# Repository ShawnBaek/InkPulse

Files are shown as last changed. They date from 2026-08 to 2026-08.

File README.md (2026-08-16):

# InkPulse

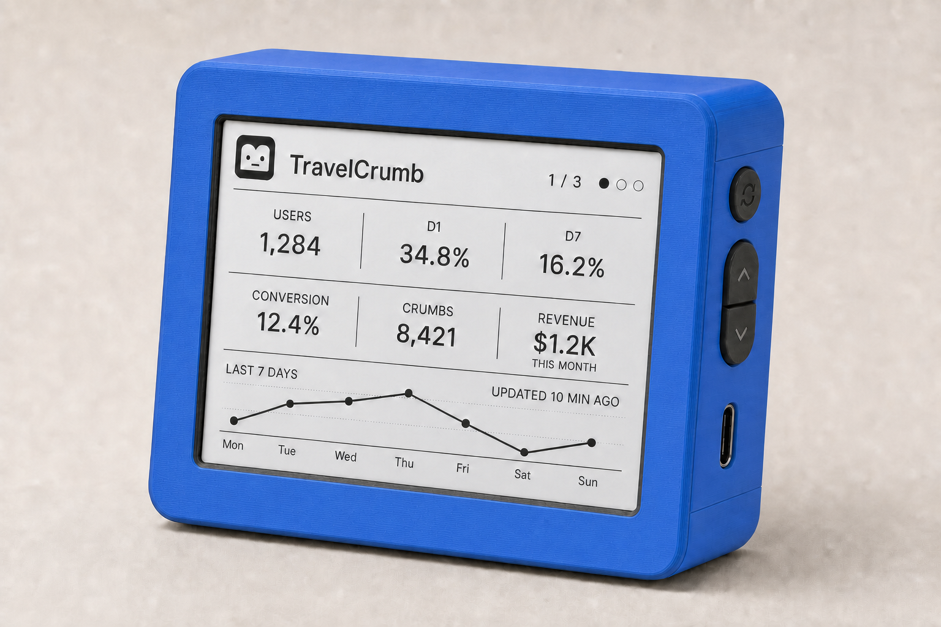
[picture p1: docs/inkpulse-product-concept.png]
Example product analytics dashboard


InkPulse is a compact desktop device that shows configurable product metrics, Google Analytics 4 retention data, and current-month App Store proceeds on a 4.2-inch e-paper display. The iPhone companion app retrieves and calculates the data, renders a 400 × 300 monochrome dashboard, and sends it to Embedded Swift firmware over Bluetooth Low Energy.

> This repository is a **v0.1 product, hardware, and 3D-printing concept**. The electrical design and battery-life target are not production specifications until they have been validated on a physical prototype.

The bundled product rendering illustrates one app-specific configuration. The app icon, product name, metric labels, and values are replaceable without changing the enclosure or display pipeline.

## Product model

| Item | v0.1 model |
| --- | --- |
| Project name | InkPulse |
| Product face | Configurable application analytics dashboard |
| Model | InkPulse Model 42 |
| Purpose | At-a-glance retention, conversion, activity, and revenue monitoring |
| Display | 4.2-inch, 400 × 300, black-and-white e-paper |
| Connectivity | Bluetooth Low Energy first; Wi-Fi is a later option |
| Update path | The iPhone renders and sends a compressed 1-bit frame |
| Controls | One action button plus a two-way previous/next rocker |
| Enclosure | Approximately 125 × 101 × 40 mm, landscape desktop format |
| Colorway | Cobalt-blue front and rear enclosure with matte-black controls and screen gasket |
| Power | USB-C 5 V or one removable protected 3.7 V 18650 cell |
| Firmware | Embedded Swift with ESP-IDF C interoperability |

The default dashboard contains:

- Total registered users
- Day 1 and Day 7 retention
- New-user-to-primary-action conversion
- Successful primary actions in the selected period
- Estimated App Store proceeds for the current calendar month
- Multi-app pagination and the current page position
- Last-successful-sync freshness, such as `UPDATED 10 MIN AGO`
- Battery and connection status

## Metric definitions

The display uses product-specific metrics instead of a generic GA4 `EVENTS` total.

| Display label | Definition | Initial data source |
| --- | --- | --- |
| `USERS` | Total registered application accounts | Application backend |
| `D1` | Percentage of a new-user cohort that returns on the next calendar day | GA4 cohort report |
| `D7` | Percentage of a new-user cohort that returns on calendar day 7 | GA4 cohort report |
| `CONVERSION` | New users who complete the application's primary action within 24 hours ÷ all new users in the same cohort | Derived from `first_open` and an app-defined success event |
| `ACTIVITY` | Successful primary actions in the selected period | GA4 `eventCount` filtered to the app-defined success event; the backend should become the production source of truth |
| `REVENUE` | Estimated developer proceeds in the current calendar month, after applicable taxes and Apple's commission | App Store Connect Sales and Trends proceeds report |
| `UPDATED … AGO` | Elapsed time since the last fully successful fetch and rendered-frame update | Companion-app sync state |

`EVENTS` is not recommended because it combines unrelated analytics events such as screen views, sessions, and button taps. `ACTIVITY` should represent the app-specific behavior the product is intended to encourage.

See [Product metrics](docs/METRICS.md) for the recommended dashboard hierarchy, formulas, and future pages.

## System architecture

```mermaid
flowchart LR
    GA4["Google Analytics Data API"] --> IOS["iPhone companion app\nSwiftUI + Core Bluetooth"]
    BACKEND["Application backend"] --> IOS
    APPSTORE["App Store Connect\nSales and Trends"] --> IOS
    IOS -->|"BLE: compressed 1-bit frame"| DEVICE["ESP32-C6\nEmbedded Swift"]
    DEVICE --> CACHE["Cached app pages\n1 / 3"]
    DEVICE -->|"SPI"| EINK["4.2-inch e-paper\n400 x 300"]
```

The device never stores Google OAuth tokens, service-account keys, or App Store Connect credentials. The iPhone app or a separate backend handles API authentication and sends only display pixels and minimal configuration to the device.

## Hardware specification

| Component | Proposed part | Key specification / reason |
| --- | --- | --- |
| MCU | Seeed Studio XIAO ESP32-C6 | 160 MHz RISC-V, 512 KB SRAM, 4 MB Flash, BLE 5.3, Wi-Fi 6, USB-C, and single-cell battery charging |
| Display | Waveshare 4.2-inch e-Paper Module V2 (B/W) | 400 × 300, SPI, partial refresh, and near-zero display retention power |
| Battery | Protected 18650 Li-ion, 3.7 V, 2,500–3,500 mAh | Removable and capable of cable-free operation |
| Battery connection | MPD BH-18650-W protected-cell holder | 77.7 × 20.9 × 21.31 mm chassis-mount holder with wire leads |
| Action input | Omron B3F-1000 tactile switch | 6 × 6 × 4.3 mm, 0.98 N, normally open |
| Navigation input | Printed two-way rocker over two Omron B3F-1000 switches | Previous/next app dashboard with separate physical contacts |
| Power switch | C&K 1101M2S5AQE2 slide switch | Right-angle SPDT with Q silver contacts rated 6 A at 28 V DC, used as a battery disconnect |
| Enclosure | 3D-printed PETG with M2 inserts and screws | Cobalt-blue front/rear shell, matte-black controls and screen gasket, electronics tray, and positively retained battery door |

### Power behavior

- With USB-C connected, the XIAO ESP32-C6 operates from USB power and charges the single-cell battery through its onboard power-management circuit.
- With USB-C disconnected, it operates from the protected 18650 cell connected to the BAT input.
- The MPD holder is designed for protected 18650 cells. Confirm the purchased cell's diameter, length, polarity, and protection circuit before installation.
- **Never charge alkaline AA/AAA cells, unprotected cells, or mixed cell types/states.** The v0.1 prototype is designed for one protected rechargeable Li-ion cell only.
- The slide switch disconnects the battery branch; USB-C can still power the controller while the battery is disconnected.
- Before designing a production PCB, validate reverse-polarity protection, branch overcurrent protection, charging temperature, actual charge current, connector polarity, and enclosure temperature.
- The initial battery-life target is at least 30 days with a 3,000 mAh cell and low-power scheduling. This is a target, not a verified claim.

See the [bill of materials](hardware/BOM.csv) and [wiring plan](hardware/WIRING.md) for component and connection details.

## Prototype purchase guide

The links below are reference purchase sources for the mechanically locked v0.1 parts. Indicative prices were checked on August 16, 2026, are shown in USD, and exclude shipping, tax, duties, tools, and any commercial 3D-printing service. Prices and availability vary by destination; these are not affiliate links.

| Part | Qty used | Reference purchase link | Listed price | Allocated to one device |
| --- | ---: | --- | ---: | ---: |
| Seeed Studio XIAO ESP32-C6 | 1 | [Seeed Studio](https://www.seeedstudio.com/Seeed-Studio-XIAO-ESP32C6-p-5884.html) | $5.20 each | $5.20 |
| Waveshare 4.2-inch e-Paper Module V2, black/white | 1 | [Waveshare](https://www.waveshare.com/4.2inch-e-paper-module.htm) | $34.99 each | $34.99 |
| EBL protected button-top 18650, 3.7 V, 3,000 mAh | 1 cell | [EBL official store](https://www.eblofficial.com/products/brc-18650-batteries) | $9.26 per 2-pack | $4.63 |
| MPD BH-18650-W holder | 1 | [DigiKey](https://www.digikey.com/en/products/detail/mpd-memory-protection-devices/BH-18650-W/3029217) | $3.64 each | $3.64 |
| C&K 1101M2S5AQE2 slide switch | 1 | [DigiKey](https://www.digikey.com/en/products/detail/c-k/SWITCH-1101M2S5AQE2/99505) | $8.48 each | $8.48 |
| Omron/Aratas B3F-1000 tactile switch | 3 | [DigiKey](https://www.digikey.com/en/products/detail/aratas-formerly-omron-components/B3F-1000/33150) | $0.35 each | $1.05 |
| Blue and black 1.75 mm PETG | About 140 g total | [Prusament PETG color range](https://prusament.com/materials/prusament-petg/) | $29.99 per 1 kg spool | About $4–5 |

The locked electronic parts total approximately **$57.99 per device**. Allow another **$12–22** per device for the allocated PETG, PTC fuse, perfboard or carrier PCB, display harness, wire, insulation, inserts, screws, nuts, foam, and consumables. The resulting **one-device prototype material estimate is $70–80**.

A first order is more expensive because the reference battery is sold as a two-pack and the blue/black enclosure requires two filament colors. Expect approximately **$120–155 at checkout** when buying two full PETG spools and normal retail packs of the remaining hardware. Subsequent units consume only a fraction of those supplies.

Before ordering, confirm that the display is the 103 × 78.5 mm black-and-white module with its SPI driver board—not a raw panel, Pico-specific board, or multicolor variant. The battery link is a dimensional reference, not an electrical certification: measure the purchased protected cell, confirm polarity and holder fit, and perform supervised charging and thermal validation. The PTC, harness, carrier, fasteners, and insulation remain intentionally supplier-neutral until the first physical fit test locks their exact models.

## 3D model

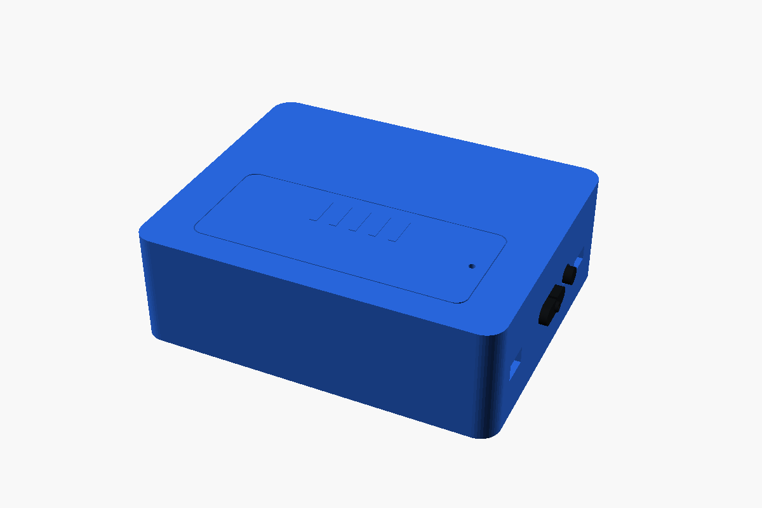
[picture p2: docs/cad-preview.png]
InkPulse OpenSCAD assembly preview


InkPulse enclosure exploded view

The repository includes the editable OpenSCAD source and printable STL exports.

- [`hardware/cad/InkPulse.scad`](hardware/cad/InkPulse.scad) — parametric source model
- `hardware/cad/stl/front-bezel.stl` — front bezel
- `hardware/cad/stl/rear-shell.stl` — rear enclosure with case standoffs and switch retention
- `hardware/cad/stl/electronics-tray.stl` — captured hardware tray and display foam lands
- `hardware/cad/stl/battery-door.stl` — rail-guided, screw-retained battery door
- `hardware/cad/stl/action-button.stl` — action/refresh button cap
- `hardware/cad/stl/navigation-rocker.stl` — pivoting previous/next rocker
- `hardware/cad/stl/switch-carrier.stl` — three-switch carrier and rocker axle support
- [`hardware/cad/README.md`](hardware/cad/README.md) — print orientation and STL export instructions
- [`hardware/cad/VALIDATION.md`](hardware/cad/VALIDATION.md) — mesh, component-stack, slicing, and physical-validation evidence

The model uses manufacturer dimensions for the Waveshare display PCB, XIAO ESP32-C6, MPD battery holder, Omron switches, and C&K power switch. It also contains visual-only component envelopes for collision inspection. That makes the repository suitable for a first engineering print, but it is not proof of physical fit: measure the purchased revisions, print the fit-critical parts, and complete an electrical and thermal prototype before treating the enclosure as production-ready.

## Software boundary

### iPhone companion app

1. The user connects the appropriate GA4 property, application backend, and App Store Connect reporting source.
2. The app reads cohort data, primary-action activity, registered-user totals, and current-month proceeds.
3. It calculates the product metrics and renders a 400 × 300 monochrome dashboard.
4. It packages one or more named app pages, compresses each frame, and sends them in BLE characteristic chunks.

### Embedded Swift firmware

1. ESP-IDF provides the BLE and SPI drivers.
2. Embedded Swift owns pairing, frame validation, and the device state machine.
3. The firmware caches the verified pages and moves to the previous or next app when the rocker is pressed.
4. It applies only complete frames to the e-paper display and then returns to deep sleep.
5. The firmware pins its Swift nightly toolchain version because the Embedded Swift ABI is not yet stable.

## v0.1 acceptance criteria

- [ ] Bring up an Embedded Swift LED and SPI test on XIAO ESP32-C6
- [ ] Show 400 × 300 full-refresh and partial-refresh test patterns
- [ ] Transfer a 15 KB frame from iPhone over BLE and validate its CRC
- [ ] Display real registered users, D1, D7, primary-action conversion, activity count, and current-month proceeds
- [ ] Cache at least three app pages and navigate them with wraparound previous/next controls
- [ ] Validate USB-C charging, battery-only boot, and low-voltage shutdown
- [ ] Print the enclosure and check display, USB-C, action button, rocker, and battery-door tolerances
- [ ] Measure a 24-hour power profile and a 30-day projected profile

## Design references

- [Embedded Swift documentation](https://docs.swift.org/embedded/documentation/embedded/) — language mode and toolchain scope
- [Integrating Embedded Swift with platforms](https://docs.swift.org/embedded/documentation/embedded/integratingwithplatforms/) — RISC-V ESP32-C3/C6/P4 support
- [Swift Embedded Examples](https://github.com/swiftlang/swift-embedded-examples) — ESP32-C6 and ESP-IDF examples
- [XIAO ESP32-C6 documentation](https://wiki.seeedstudio.com/xiao_esp32c6_getting_started/) — memory, wireless, USB-C, and battery power
- [Waveshare 4.2-inch e-Paper documentation](https://www.waveshare.com/wiki/4.2inch_e-Paper_Module_Manual) — dimensions, resolution, SPI, and refresh behavior
- [MPD BH-18650-W drawing](https://www.memoryprotectiondevices.com/datasheets/BH-18650-W/BH-18650-W-datasheet.pdf) — protected-cell holder envelope and mounting pattern
- [Omron B3F tactile-switch datasheet](https://omronfs.omron.com/en_US/ecb/products/pdf/en-b3f.pdf) — action and navigation switch dimensions and travel
- [C&K 1000 Series slide-switch datasheet](https://www.ckswitches.com/media/1429/1000.pdf) — `1101M2S5AQE2` dimensions, ordering code, and Q-contact rating
- [Google Analytics Data API quickstart](https://developers.google.com/analytics/devguides/reporting/data/v1/quickstart) — GA4 authentication and `runReport`
- [App Store Connect Sales and Trends metrics](https://developer.apple.com/help/app-store-connect/reference/reporting/sales-and-trends-metrics-and-dimensions/) — proceeds definition and reporting dimensions
- [Apple Core Bluetooth](https://developer.apple.com/documentation/corebluetooth) — iPhone BLE communication

## Repository structure

```text
InkPulse/
├── docs/                  # Product renderings, App Store icon, and diagrams
├── hardware/
│   ├── BOM.csv            # v0.1 bill of materials
│   ├── WIRING.md          # Power and SPI connections
│   └── cad/               # OpenSCAD source and STL exports
└── README.md
```

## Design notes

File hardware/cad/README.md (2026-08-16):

# InkPulse enclosure CAD

`InkPulse.scad` is the parametric source of truth. It models a 125 × 101 × 40 mm landscape, FDM-printable enclosure around specific component envelopes. This is a prototype design: physical print and assembly validation are required before production use.

## Component envelopes

| Part | Envelope / feature |
| --- | --- |
| Waveshare 4.2-inch B/W V2 e-Paper | 103.0 × 78.5 × 8.5 mm PCB envelope; 84.8 × 63.6 mm active area; 90.1 × 77.0 × 1.18 mm raw panel |
| Seeed XIAO ESP32-C6 | 17.8 × 21.0 × 4.0 mm; 11.0 × 5.5 mm USB-C plug opening |
| MPD BH-18650-W | 77.7 × 20.9 × 21.31 mm; Ø3.2 mm mounting holes, 55.61 mm centres |
| Omron B3F-1000 | 6.0 × 6.0 × 4.3 mm; three positions: action, previous, next |
| C&K 1101M2S5AQE2 | 13.21 × 9.53 × 4.72 mm right-angle envelope plus actuator; 10 × 6 mm conservative right-side opening; Q silver contacts rated 6 A at 28 V DC |

The display pocket locates the PCB with 0.30 mm clearance per side. Four electronics-tray lands use 0.5 mm foam squares at PCB corners only; never clamp the e-paper glass. The purchased module revision, FPC bend, protected-cell dimensions and connector height must be measured before final printing.

## Printable parts

- `front_bezel`: viewing frame, display pocket, four M2 insert bosses.
- `rear_shell`: front-open shell, fully through-cut USB-C/power/button openings, four long case-screw standoffs, slide-in switch-carrier guides, power-switch retainer, door insert boss and door rails.
- `electronics_tray`: case-screw capture holes, four PCB foam lands, MPD holder rim and mounting holes, XIAO snap cradle, wire channels and battery-end routes.
- `battery_door`: flush rear door with matching rail tongues, grip ribs, and one positive M2 retaining screw.
- `action_button`: side cap.
- `navigation_rocker`: central pivot bore and two actuator nubs; its stops target 0.35–0.45 mm motion for the B3F's 0.25 mm pretravel.
- `switch_carrier`: three wire-soldered B3F pockets and the rocker's internal alignment backer.

`assembly` and `exploded` are visual inspection views with a TravelCrumb-blue enclosure, matte-black controls, and colored hardware envelopes; do not print them.

## Hardware and assembly

1. Print the seven parts and install four nominal 3.6 mm OD × 4.2 mm deep M2 heat-set inserts in the front-bezel bosses plus one matching insert in the rear-shell battery-door boss.
2. Install the e-paper PCB in the bezel. Apply the 0.5 mm foam squares to the four electronics-tray lands before closing; they must touch only PCB corners.
3. Attach the BH-18650-W to the tray with two #2-56 × 1/4 inch fasteners and nuts, solder and strain-relieve both holder leads, then seat the XIAO in its cradle and route wires through the tray channels.
4. Solder leads to the three B3F-1000 switches, install them in the switch carrier, slide the carrier into the rear-shell guides from the open front, fit the action cap, and use 1.7–1.8 mm steel pin/filament as the rocker axle.
5. Slide the C&K `1101M2S5AQE2` power switch into its internal retainer, insulate and strain-relieve its soldered terminals, then capture the electronics tray between the front bosses and rear standoffs while joining the shell with four M2 × 30 mm screws. Insert a polarity-checked protected cell, engage the door rails, and secure the door with one M2 × 6 mm screw into the fifth heat-set insert.

The holder's open face is at the rear door. A protected cell is mandatory, but protected-cell length and diameter vary: confirm it fits the purchased MPD holder. Verify USB-C insertion and charging current. The XIAO charger is not a substitute for a complete battery safety review or thermal test.

## Export

```sh
mkdir -p stl
openscad -o stl/front-bezel.stl -D 'part="front_bezel"' InkPulse.scad
openscad -o stl/rear-shell.stl -D 'part="rear_shell"' InkPulse.scad
openscad -o stl/electronics-tray.stl -D 'part="electronics_tray"' InkPulse.scad
openscad -o stl/battery-door.stl -D 'part="battery_door"' InkPulse.scad
openscad -o stl/action-button.stl -D 'part="action_button"' InkPulse.scad
openscad -o stl/navigation-rocker.stl -D 'part="navigation_rocker"' InkPulse.scad
openscad -o stl/switch-carrier.stl -D 'part="switch_carrier"' InkPulse.scad
```

## Print setup

- 0.4 mm nozzle, 0.20 mm layers, three walls, four top/bottom layers, 15–20% gyroid infill.
- Bezel: front face down on a smooth plate. Rear shell: rear/back face down; supports may be needed under right-side openings and internal rails.
- Tray: large plate down. Door and caps: visible outer face down. Switch carrier: broad face down.
- Start with 0.0 mm XY compensation. Ream holes only as needed; do not force the rocker pivot.

## CAD verification limits

Watertight STL and slicer checks validate mesh topology and printable geometry only. They do not validate printer tolerance, connector force, antenna performance, electrical safety, battery fit, FPC clearance, screw pull-out, or long-term wear. Physical print, fit and assembly validation are still required.

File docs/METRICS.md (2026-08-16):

# TravelCrumb product metrics

InkPulse should answer three questions at a glance:

1. Are people returning?
2. Are they reaching the core TravelCrumb behavior?
3. Is the product generating revenue?

## Recommended primary screen

| Priority | Metric | Why it belongs on the device |
| --- | --- | --- |
| 1 | First-crumb conversion | Measures whether new users discover and complete the core behavior |
| 2 | D1 retention | Gives the earliest signal that the first experience is useful |
| 3 | D7 retention | Shows whether TravelCrumb is becoming a repeat habit |
| 4 | CRUMBS | Counts successful uses of the core behavior, not generic instrumentation traffic |
| 5 | USERS | Provides the total registered-account scale without duplicating retention |
| 6 | Current-month proceeds | Adds a direct business outcome without duplicating retention or activity |

The current product rendering uses this six-metric set.

### USERS

`USERS` is the total number of registered TravelCrumb accounts, read from the backend. It is intentionally not WAU: D1 and D7 already occupy the limited screen space used for engagement and retention signals.

## Exact definitions

### First-crumb conversion

```text
new users who create their first successful crumb within 24 hours
-----------------------------------------------------------------
all new users in the same acquisition cohort
```

This is a product activation metric. It is different from App Store conversion.

### App Store conversion

```text
downloads or redownloads
------------------------
unique App Store product-page views
```

Apple provides this metric in App Store Connect Analytics. It is useful for icon, screenshot, and acquisition work, but it does not show whether users find value after installation. It should appear on a separate acquisition page rather than replace first-crumb conversion on the primary product page.

### D1 and D7 retention

- `D1`: users acquired on day 0 who return on the next calendar day ÷ the day-0 cohort.
- `D7`: users acquired on day 0 who return on calendar day 7 ÷ the day-0 cohort.
- Use the GA4 property timezone and standard, non-rolling cohort calculation unless the implementation explicitly states otherwise.

### CRUMBS

Count only a successful persisted crumb. Do not increment the metric when the composer opens, validation fails, saving fails, or a duplicate analytics event is retried.

For a prototype, GA4 can count a single `crumb_created` event emitted after persistence succeeds. For production, a deduplicated backend count should be the source of truth.

### Current-month proceeds

```text
estimated developer proceeds for the current calendar month
```

Show this as `REVENUE`, with `THIS MONTH` directly below the amount. The initial source is the App Store Connect Sales and Trends proceeds report. Apple defines proceeds as the estimated amount the developer receives after the customer price is reduced by applicable taxes and Apple's commission. Do not label this value as MRR unless TravelCrumb has recurring subscription revenue and the implementation deliberately calculates MRR.

The on-screen amount is a compact estimate. Financial reconciliation still belongs in App Store Connect and the accounting system. App Store Connect credentials stay in the iPhone companion app or backend, never on the e-paper device.

### Freshness

`UPDATED 10 MIN AGO` means ten minutes have elapsed since the last fully successful data synchronization and rendered frame. A failed refresh must not reset this clock. When the last successful sync is older than the product threshold, replace the relative label with a visible stale state rather than implying that the dashboard is current.

## Useful secondary metrics

These are valuable, but the 400 × 300 primary screen should not show all of them at once.

### Product page

- Crumbs per weekly active user
- Percentage of users creating at least two crumbs in seven days
- D30 retention after enough cohort volume exists
- Budget created or completed, if budget usage is a strategic goal
- Photo, map, or currency feature adoption

### Reliability page

- Crash-free users and crash-free sessions by current release
- Sync success rate
- Crumb-save failure rate
- API error rate and p95 latency
- Latest-version adoption

### Acquisition page

- App Store product-page conversion
- First-time downloads
- Product-page views
- Source or campaign performance

## Implementation cautions

- Do not compare tiny cohorts without displaying the cohort size.
- Do not calculate conversion from raw event totals; deduplicate by user and successful outcome.
- Do not combine App Store conversion and first-crumb conversion under the same unlabeled definition.
- Keep a fixed seven-day window for CRUMBS; USERS remains an all-time registered total and REVENUE uses the current calendar month.
- Render the last-successful-sync age on every page and do not update it after a failed fetch.

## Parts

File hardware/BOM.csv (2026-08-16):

Category | Part | Selected model | Qty | Required | Mechanical envelope / notes
Controller | MCU board | Seeed Studio XIAO ESP32-C6 | 1 | Yes | 21.0 x 17.8 mm PCB; USB-C; 3.7 V BAT input and onboard charging
Display | E-paper | Waveshare 4.2inch e-Paper Module V2 B/W | 1 | Yes | 103.0 x 78.5 mm driver PCB; 90.1 x 77.0 x 1.18 mm raw panel; 84.8 x 63.6 mm active area
Battery | Protected Li-ion cell | Protected button-top 18650 3.7 V | 1 | Yes | Use one qualified rechargeable protected cell; verify the selected cell fits the MPD holder before assembly
Battery holder | Protected-cell holder | MPD BH-18650-W | 1 | Yes | 77.7 x 20.9 x 21.31 mm; 55.61 mm mounting centers; two 3.2 mm holes; 24 AWG leads
Switch | Power disconnect | C&K 1101M2S5AQE2 | 1 | Yes | Right-angle SPDT; black S5 actuator; Q silver contacts rated 6 A at 28 V DC; use common and one throw as battery disconnect
Button | Action input | Omron B3F-1000 | 1 | Yes | 6 x 6 x 4.3 mm; 0.98 N; 0.25 mm nominal pretravel
Button | Navigation input | Omron B3F-1000 | 2 | Yes | Separate previous and next contacts under the printed rocker
Interconnect | Display cable | 8-conductor female jumper or custom harness | 1 | Yes | Keep SPI wiring short and provide strain relief
Carrier | Switch carrier | 1.6 mm perfboard or custom carrier PCB | 1 | Yes | Supports three rotated B3F-1000 switches behind the right-side controls
Protection | Resettable fuse | PTC 0.5-1.0 A hold | 1 | Recommended | Prototype battery-branch overcurrent protection
Fasteners | Case inserts | M2 heat-set insert 3.5 mm OD x 4.0 mm L | 5 | Yes | Four case joints plus one battery-door retention point; confirm pilot holes with the purchased insert
Fasteners | Case screws | M2 x 30 mm button-head machine screw | 4 | Yes | Rear-access screws pass through printed standoffs and the tray into front-bezel inserts
Fasteners | Battery-door screw | M2 x 6 mm captive or retained machine screw | 1 | Yes | Positive retention for the removable door
Fasteners | Battery-holder screws | #2-56 x 1/4 inch machine screw with nut | 2 | Yes | Matches MPD's chassis-mount recommendation; verify tray thickness and thread engagement
Enclosure | Filament | PETG 1.75 mm | 1 | Yes | 0.4 mm nozzle target; PETG preferred for clips and a warmer enclosure
Insulation | Cell insulation | Fish-paper ring and insulating sheet | 1 | Recommended | Prevent holder leads or hardware from contacting the cell casing
Compliance | Prototype validation | Physical fit electrical and thermal test | 1 | Yes | Printable CAD and slicing checks do not certify the assembled product

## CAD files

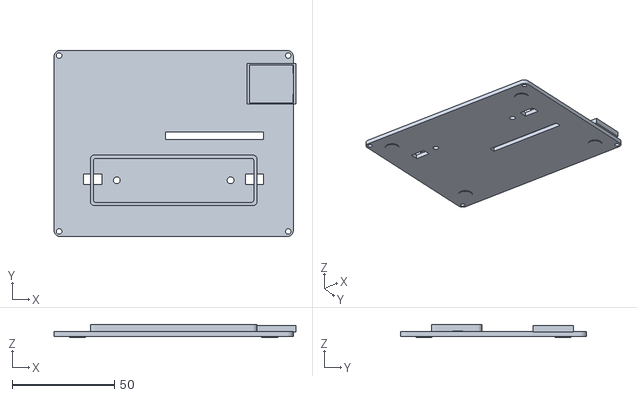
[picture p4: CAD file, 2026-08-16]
hardware/cad/stl/electronics-tray.stl
118.3 x 91.0 x 6.35

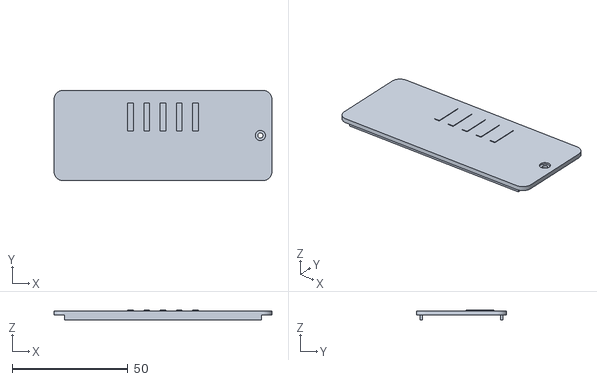
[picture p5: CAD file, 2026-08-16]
hardware/cad/stl/battery-door.stl
94.0 x 39.0 x 4.10

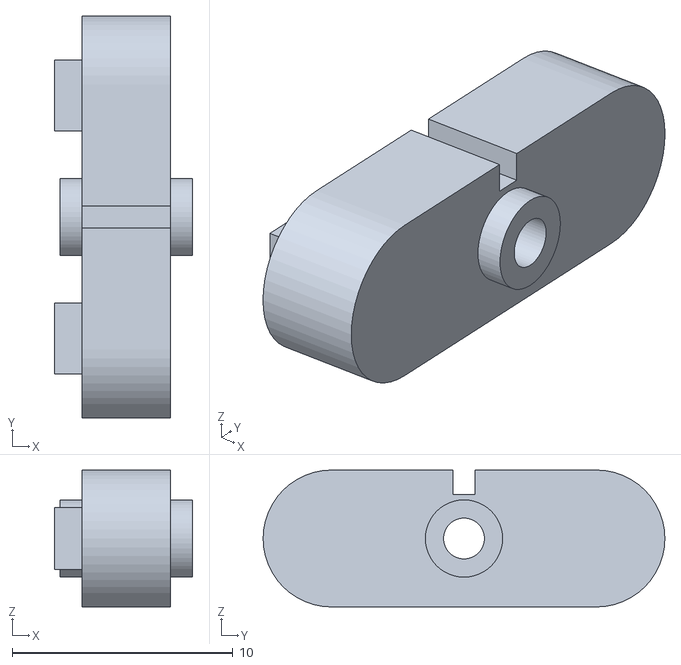
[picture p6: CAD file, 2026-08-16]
hardware/cad/stl/navigation-rocker.stl
6.25 x 18.2 x 6.20

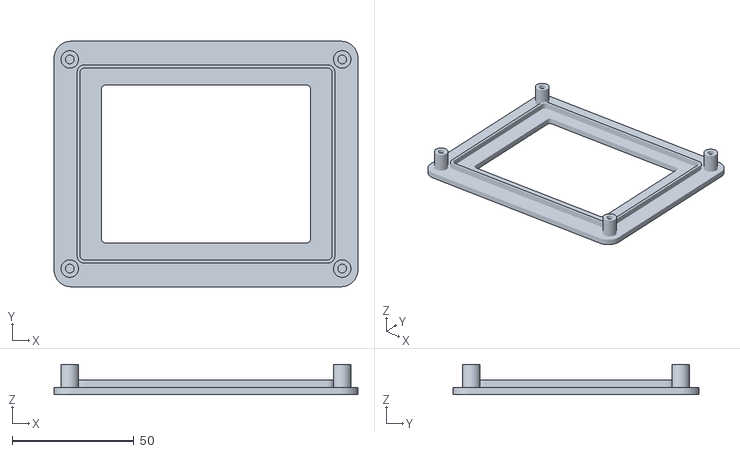
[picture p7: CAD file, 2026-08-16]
hardware/cad/stl/front-bezel.stl
125.0 x 101.0 x 12.5

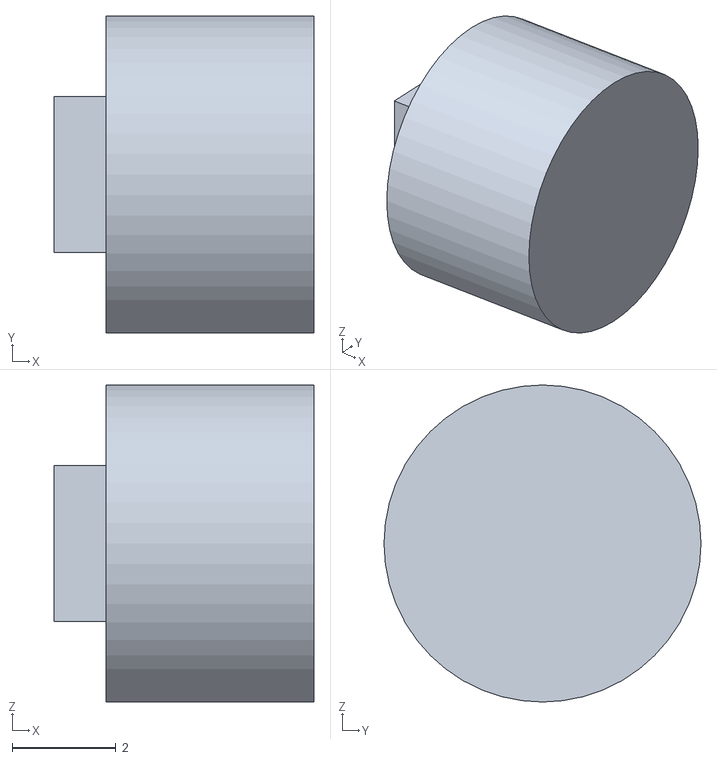
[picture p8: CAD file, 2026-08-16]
hardware/cad/stl/action-button.stl
5.00 x 6.10 x 6.10

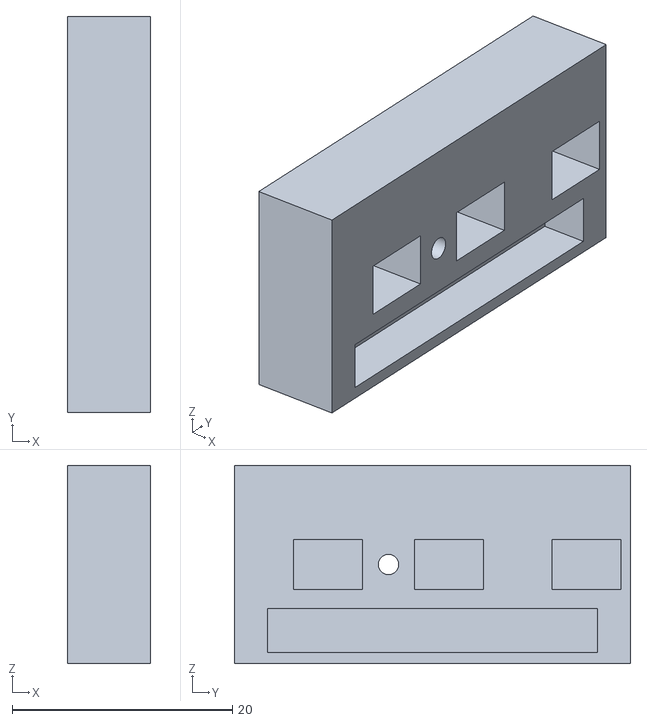
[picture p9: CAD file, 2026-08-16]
hardware/cad/stl/switch-carrier.stl
7.50 x 36.0 x 18.0

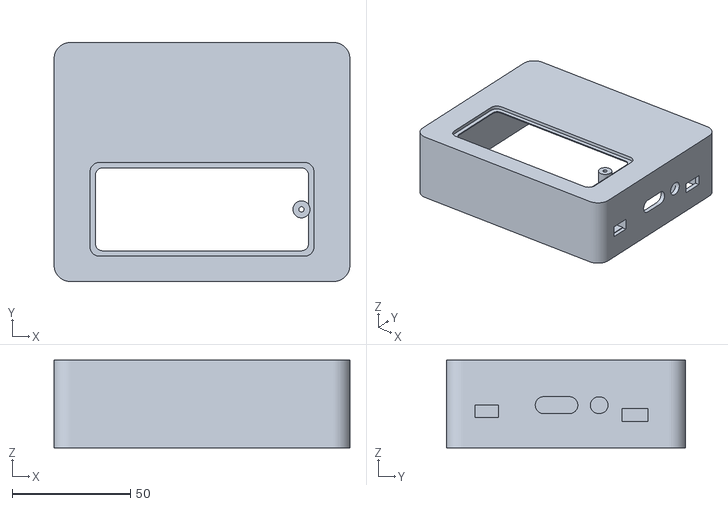
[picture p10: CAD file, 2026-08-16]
hardware/cad/stl/rear-shell.stl
125.0 x 101.0 x 37.0

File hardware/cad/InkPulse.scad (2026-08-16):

// InkPulse Model 42 — assembly-oriented FDM enclosure. Units: mm.
// Export: openscad -o stl/front-bezel.stl -D 'part="front_bezel"' InkPulse.scad
$fn=48;
part="assembly"; // front_bezel,rear_shell,electronics_tray,battery_door,action_button,navigation_rocker,switch_carrier,assembly,exploded

// FDM design parameters
outer_w=125; outer_h=101; outer_d=40; front_d=3; wall=2.4; back_wall=2.4; corner_r=7;
fit=0.30; m2_clear=2.25; m2_insert_od=3.6; m2_insert_depth=4.2;
// Locked purchased-component envelopes (measure the actual purchased revision)
epd_pcb=[103,78.5,8.5]; epd_active=[84.8,63.6]; epd_panel=[90.1,77,1.18];
xiao=[21,17.8,4]; battery_holder=[77.7,20.9,21.31]; battery_hole_pitch=55.61;
switch_body=[6,6,4.3]; window=[86,64.8]; boss_xy=[[-56,-43],[56,-43],[-56,43],[56,43]];
power_switch_body=[13.21,9.53,4.72]; power_switch_frame=[14.9,11.2,7.0];
tray_z=12.0; battery_pos=[0,-18]; xiao_pos=[47.8,29.1];
action_y=14; nav_y=-4; switch_z=18; door_center=[0,-20]; door_size=[94,39]; door_t=1.8; door_screw=[42,-20];
rear_local_d=outer_d-front_d; tray_t=2.4; tray_base_z=.5; tray_rear_z=tray_z+tray_base_z+tray_t;
carrier_x=outer_w/2-wall-3.75; switch_center_x=carrier_x+.375;
carrier_h=36; power_switch_x=outer_w/2-wall-power_switch_frame[0]/2+.3; power_switch_y=-33.45;

module rounded_prism(s,r){linear_extrude(height=s[2]) offset(r=r) square([s[0]-2*r,s[1]-2*r],center=true);}
module m2_boss(x,y,z0=front_d,h=9.5){difference(){translate([x,y,z0])cylinder(h=h,d=7.2);translate([x,y,z0+h-m2_insert_depth+.01])cylinder(h=m2_insert_depth+.1,d=m2_insert_od);}}
module side_slot(y,z,len,dia,depth=wall+1){hull()for(yy=[y-len/2+dia/2,y+len/2-dia/2])translate([outer_w/2-wall-.1,yy,z])rotate([0,90,0])cylinder(h=depth,d=dia);}
module rear_standoff(x,y){
 standoff_z=tray_rear_z-front_d;
 difference(){
  translate([x,y,standoff_z])cylinder(h=rear_local_d-standoff_z,d=7.2);
  translate([x,y,standoff_z-.1])cylinder(h=rear_local_d-standoff_z+.3,d=m2_clear);
  translate([x,y,rear_local_d-1.25])cylinder(h=1.4,d=4.5);
 }}
module door_insert_boss(){
 z0=rear_local_d-back_wall-m2_insert_depth;
 difference(){
  translate([door_screw[0],door_screw[1],z0])cylinder(h=back_wall+m2_insert_depth,d=7.2);
  translate([door_screw[0],door_screw[1],z0-.1])cylinder(h=m2_insert_depth+.2,d=m2_insert_od);
  translate([door_screw[0],door_screw[1],rear_local_d-back_wall-.1])cylinder(h=back_wall+.3,d=m2_clear);
 }}
module power_switch_retainer(){
 // Slide-in frame for the C&K 1000-series right-angle body; secure after fit check.
 translate([power_switch_x,power_switch_y,15.5])difference(){
  cube(power_switch_frame,center=true);
  cube([power_switch_frame[0]+.3,power_switch_body[1]+2*fit,power_switch_body[2]+2*fit],center=true);
 }}
module switch_carrier_guides(){
 // The carrier slides in from the open front before the bezel is installed.
 for(yy=[-carrier_h/2-.5,carrier_h/2+.5])translate([carrier_x,yy,switch_z])cube([7.9,.7,18],center=true);
 translate([carrier_x,0,switch_z+9.8])cube([7.9,carrier_h+1.0,1.2],center=true);
}

module front_bezel(){difference(){union(){rounded_prism([outer_w,outer_h,front_d],corner_r);
 translate([0,0,front_d-.01])difference(){rounded_prism([epd_pcb[0]+2*fit+2.4,epd_pcb[1]+2*fit+2.4,3],3);translate([0,0,-.1])rounded_prism([epd_pcb[0]+2*fit,epd_pcb[1]+2*fit,3.2],2);}
 for(p=boss_xy)m2_boss(p[0],p[1]);}
 translate([0,0,-.1])rounded_prism([window[0],window[1],front_d+.2],1.6);
 translate([0,0,front_d-.01])rounded_prism([epd_panel[0]+2*fit,epd_panel[1]+2*fit,2.2],1.6);}}

module rear_shell(){union(){difference(){union(){rounded_prism([outer_w,outer_h,rear_local_d],corner_r);
 // matching door rails
 for(yy=[door_center[1]-door_size[1]/2+2.2,door_center[1]+door_size[1]/2-2.2])translate([door_center[0],yy,rear_local_d-1.9])cube([door_size[0]-8,1.2,2.1],center=true);}
 // front-open main cavity
 translate([0,0,-.1])rounded_prism([outer_w-2*wall,outer_h-2*wall,rear_local_d-back_wall+.2],corner_r-wall);
 // USB-C and right-angle power switch openings
 translate([outer_w/2-wall/2,xiao_pos[1],tray_rear_z-front_d+xiao[2]/2])cube([wall+1,11,5.5],center=true);
 translate([outer_w/2-wall/2,power_switch_y,15.5])cube([wall+1,10,6],center=true);
 side_slot(action_y,switch_z,7.5,7); side_slot(nav_y,switch_z,18,7.2);
 // battery door and flush rebate
 translate([door_center[0],door_center[1],outer_d-front_d-back_wall-.1])rounded_prism([door_size[0]-4,door_size[1]-4,back_wall+.3],3);
 translate([door_center[0],door_center[1],outer_d-front_d-door_t])rounded_prism([door_size[0]+2*fit,door_size[1]+2*fit,door_t+.2],4);
 translate([door_screw[0],door_screw[1],rear_local_d-back_wall-.1])cylinder(h=back_wall+.3,d=m2_clear);}
 for(p=boss_xy)rear_standoff(p[0],p[1]);
 door_insert_boss();
 power_switch_retainer();
 switch_carrier_guides();}}

module electronics_tray(){difference(){union(){translate([0,0,tray_base_z])rounded_prism([117,91,tray_t],3);
 // Printed lands sit 0.5 mm behind the PCB; add 0.5 mm foam at these corners only.
 for(p=[[-47,-34],[47,-34],[-47,34],[47,34]])translate([p[0],p[1],0])cylinder(h=tray_base_z+.15,d=8);
 // holder rim with rear-facing open battery face
 difference(){translate([battery_pos[0],battery_pos[1],tray_base_z+tray_t-.05])rounded_prism([battery_holder[0]+2*fit+3.2,battery_holder[1]+2*fit+3.2,3.5],2);translate([battery_pos[0],battery_pos[1],tray_base_z+tray_t-.15])rounded_prism([battery_holder[0]+2*fit,battery_holder[1]+2*fit,3.7],1);}
 // low XIAO snap cradle; tabs avoid the antenna end
 translate([xiao_pos[0],xiao_pos[1],tray_base_z+tray_t+1.4])difference(){cube([xiao[0]+2*fit+2.4,xiao[1]+2*fit+1.4,3],center=true);cube([xiao[0]+2*fit,xiao[1]+2*fit,3.3],center=true);}
 for(yy=[-7,7])translate([xiao_pos[0]+xiao[0]/2+fit+.4,xiao_pos[1]+yy,tray_base_z+tray_t+1.3])cube([1.1,4,2.2],center=true);}
 for(p=boss_xy)translate([p[0],p[1],-.1])cylinder(h=tray_base_z+tray_t+.3,d=2.7);
 for(x=[-battery_hole_pitch/2,battery_hole_pitch/2])translate([battery_pos[0]+x,battery_pos[1],-.1])cylinder(h=tray_base_z+tray_t+.3,d=3.35);
 // open wiring channels and end strain-relief routes
 translate([-4,2,-.1])cube([48,3.5,tray_base_z+tray_t+.3]); translate([-44,-20,-.1])cube([9,5,tray_base_z+tray_t+.3]);translate([35,-20,-.1])cube([9,5,tray_base_z+tray_t+.3]);}}

module battery_door(){difference(){union(){rounded_prism([door_size[0],door_size[1],door_t],4);for(yy=[-door_size[1]/2+2.2,door_size[1]/2-2.2])translate([0,yy,-1])cube([door_size[0]-9,1,2.1],center=true);for(x=[-14,-7,0,7,14])translate([x,8,door_t])cube([2.5,12,.5],center=true);}translate([door_screw[0],0,-.1])cylinder(h=door_t+.3,d=m2_clear);translate([door_screw[0],0,door_t-.7])cylinder(h=.9,d=4.4);}}
module action_button(){union(){rotate([0,90,0])cylinder(h=4,d=6.1,center=true);translate([-2.2,0,0])cube([1.6,3,3],center=true);}}
module navigation_rocker(){difference(){union(){hull()for(yy=[-6,6])translate([0,yy,0])rotate([0,90,0])cylinder(h=4,d=6.2,center=true);rotate([0,90,0])cylinder(h=6,d=3.5,center=true);for(yy=[-5.5,5.5])translate([-2.5,yy,0])cube([1.5,3.2,2.8],center=true);}translate([0,0,0])rotate([0,90,0])cylinder(h=7,d=1.85,center=true);translate([0,0,2.6])cube([4.5,1,1.2],center=true);}}
module switch_carrier(){difference(){cube([7.5,carrier_h,18],center=true);
 // Open-side pockets retain the switch backs while leaving a 0.75 mm inner web.
 for(yy=[nav_y-5.5,nav_y+5.5,action_y])translate([.375,yy,0])cube([6.75,6.25,4.5],center=true);
 translate([1.8,0,-6])cube([4,30,4],center=true);
 // A shared 1.7–1.8 mm axle passes through this support and the rocker barrel.
 translate([0,nav_y,0])rotate([0,90,0])cylinder(h=9,d=1.85,center=true);}}
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

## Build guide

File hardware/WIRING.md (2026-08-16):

# InkPulse Rev A prototype wiring

This is a prototype wiring plan, not a certified charging or production schematic. Disconnect the cell before rewiring and verify the holder lead polarity with a multimeter.

## E-paper SPI

| Waveshare 4.2″ pin | XIAO ESP32-C6 | Purpose |
| --- | --- | --- |
| VCC | 3V3 | Display logic and module power |
| GND | GND | Common ground |
| DIN | D10 / GPIO18 | SPI MOSI |
| CLK | D8 / GPIO19 | SPI clock |
| CS | D7 / GPIO17 | Chip select |
| DC | D6 / GPIO16 | Data/command |
| RST | D5 / GPIO23 | Display reset |
| BUSY | D4 / GPIO22 | Display busy input |

The e-paper module does not need MISO. Confirm the purchased board revision and its voltage selector before applying power.

## Buttons

- Use three Omron `B3F-1000` normally-open tactile switches on the internal switch carrier.
- Connect the action button between `D0 / GPIO0` and `GND`.
- Connect the previous half of the navigation rocker between `D1 / GPIO1` and `GND`.
- Connect the next half of the navigation rocker between `D2 / GPIO2` and `GND`.
- Configure all three GPIOs with internal pull-ups and debounce them in firmware.
- GPIO0, GPIO1, and GPIO2 are RTC-capable on ESP32-C6, so all three controls can be configured as deep-sleep wake sources.
- A short action-button press requests a refresh; a 5-second hold clears pairing after a confirmation pattern.
- Previous/next presses move through cached app pages with wraparound navigation.

## Battery and USB-C

```text
MPD BH-18650-W red lead (+) -> PTC fuse -> C&K 1101M2S5AQE2 COM
C&K selected throw ------------------------------------------> XIAO BAT (+)
MPD BH-18650-W black lead (-) ----------------> XIAO BAT (-/GND)
USB-C 5 V ------------------------------------> XIAO USB-C connector
```

Use only one protected, rechargeable 3.7 V Li-ion cell. The battery branch must not be wired to the USB 5 V pin. The XIAO board's battery input and charger are the only intended meeting point for USB and battery power in Rev A. The SPDT switch is used as a simple disconnect: leave its unused throw electrically isolated.

The XIAO documentation states that battery power is supported and that USB-C charges a connected 3.7 V lithium battery. It also states that the 5 V pin is not powered in battery mode. The selected C&K switch uses Q silver contacts rated 6 A at 28 V DC, providing substantial margin over the prototype battery branch, but wiring, insulation, and thermal behavior still require physical validation. Validate the purchased board revision, charge current, cell temperature, and low-voltage behavior on the physical prototype.

## Before first power-on

1. Confirm the MPD holder's lead polarity without the XIAO connected.
2. Confirm that the selected protected cell fits without excessive spring force or damaged insulation.
3. Confirm there is no short between BAT+ and GND in either switch position.
4. Boot from USB-C without the display and verify 3.3 V.
5. Boot from USB-C with the display and show a static test pattern.
6. Connect the protected cell with USB-C disconnected and verify battery-only boot.
7. Verify action, previous, and next each wake the controller from deep sleep.
8. Observe the first USB-C charge on a nonflammable surface and check cell, holder, wiring, and board temperature.

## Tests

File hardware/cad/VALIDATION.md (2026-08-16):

# CAD and slicing validation

Validation date: 2026-08-16

## Result

The seven STL files are valid, single-part, watertight meshes and all seven slice successfully with a generic 0.4 mm FDM profile. The enclosure stack is dimensioned around selected manufacturer component envelopes and is suitable for a first engineering print.

This is not physical-fit or production validation. No enclosure in this repository has yet been printed and assembled with the purchased display, controller, protected cell, switches, wiring, and fasteners.

## Hardware envelope checks

| Check | Result |
| --- | --- |
| Display PCB | 103.0 × 78.5 mm inside a pocket with 0.30 mm clearance per side |
| Display stack | Conservative 8.5 mm module envelope from global Z 3.0 to 11.5 mm |
| Foam / tray interface | 0.5 mm between the module rear envelope and the four tray lands |
| MPD BH-18650-W | 77.7 × 20.9 × 21.31 mm; rear stack from Z 14.9 to 36.21 mm |
| Battery-holder rear clearance | 1.39 mm to the nominal inside face of the rear wall |
| XIAO ESP32-C6 | 17.8 × 21.0 × 4.0 mm; USB-C opening centered on the board envelope |
| XIAO cradle neighbors | Nominal 0.30 mm to the inner side wall, 0.35 mm to the switch-carrier guide, and 0.40 mm to the upper-right case standoff |
| Power switch | C&K 1101M2S5AQE2 in a 13.21 × 9.53 × 4.72 mm right-angle body envelope, with a 10 × 6 mm side opening and slide-in retainer |
| Power-switch retainer | Nominal 0.35 mm separation from the lower-right case standoff |
| Case joints | Four rear standoffs capture the tray against front bosses; M2 × 30 mm screws provide about 2.5 mm nominal insert engagement |
| Battery door | Two rails plus one M2 × 6 mm screw into a dedicated heat-set insert |
| Navigation control | Two B3F-1000 switch pockets, a carrier axle bore, rocker barrel, actuator nubs, and motion stops |

The 8.5 mm display depth is deliberately conservative because Waveshare publishes the PCB and panel outline but not a single maximum assembled height covering every module revision and connector. Measure the purchased module before the full print.

## Mesh validation

OpenSCAD 2021.01 exported the models. ADMesh 0.98.5 reported one connected part, zero disconnected facets, zero bad edges, and zero degenerate facets for every file.

| STL | Bounding box (mm) | Connected parts |
| --- | --- | --- |
| `front-bezel.stl` | 125.0 × 101.0 × 12.5 | 1 |
| `rear-shell.stl` | 125.0 × 101.0 × 37.0 | 1 |
| `electronics-tray.stl` | 118.3 × 91.0 × 6.35 | 1 |
| `battery-door.stl` | 94.0 × 39.0 × 4.10 | 1 |
| `action-button.stl` | 5.0 × 6.10 × 6.10 | 1 |
| `navigation-rocker.stl` | 6.25 × 18.2 × 6.20 | 1 |
| `switch-carrier.stl` | 7.5 × 36.0 × 18.0 | 1 |

## Slicing validation

PrusaSlicer 2.9.6 sliced each part with a generic 250 × 210 mm FDM bed, 0.4 mm nozzle, 0.20 mm layer height, three perimeters, four top/bottom layers, 15% gyroid infill, and automatic supports.

| Part | Test orientation | Estimated time | Filament | Automatic support generated |
| --- | --- | ---: | ---: | --- |
| Front bezel | Front face on bed | 2 h 26 m 15 s | 7,107.58 mm | No |
| Rear shell | Back face on bed | 6 h 37 m 16 s | 24,450.40 mm | Yes |
| Electronics tray | Main plate on bed | 3 h 0 m 19 s | 9,423.69 mm | Yes |
| Battery door | Outer face on bed | 54 m 59 s | 2,901.35 mm | Yes |
| Action button | Outer round face on bed | 2 m 2 s | 54.97 mm | No |
| Navigation rocker | Outer face on bed | 6 m 13 s | 260.95 mm | Yes |
| Switch carrier | Broad face on bed | 23 m 8 s | 1,232.24 mm | Yes |
| **Total** | Separate jobs | **13 h 30 m 12 s** | **45,431.18 mm** | — |

Estimates depend on printer, PETG profile, speeds, support settings, and cooling. The generated G-code was temporary and is not committed because it is printer-specific.

## Required physical validation

1. Print the action button, rocker, switch carrier, and a short side-wall fit coupon first. Verify switch preload and 0.35–0.45 mm rocker motion.
2. Dry-fit the unpowered Waveshare module, FPC/connector, XIAO board, MPD holder, protected cell, power switch, and fasteners.
3. Check that foam lands touch PCB corners only and never load the e-paper glass.
4. Confirm USB-C plug insertion, battery removal, door screw engagement, carrier-guide retention, and all wire bend radii.
5. Run battery-only boot and supervised USB-C charging on a nonflammable surface. Measure current and cell, holder, controller, and enclosure temperatures.
6. Check Wi-Fi/BLE performance with the final cell and wiring installed before freezing the enclosure material or antenna-side wall thickness.

Only after those checks pass should the model be described as physically validated or production-ready.

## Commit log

2026-08-16 feat: Add InkPulse e-paper dashboard concept
    Define the TravelCrumb product metrics, multi-app controls, power plan,
    and printable enclosure so the idea can move into physical prototyping.
    [BOM.csv, InkPulse.scad, battery-door.stl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]
2026-08-16 feat: Redesign enclosure around selected hardware
    Base the printable enclosure on selected display, controller, battery, switch, and fastener envelopes. Add captured trays, serviceable controls, and documented mesh and slicer validation.
    Refresh the TravelCrumb dashboard render with blue front and rear hardware, product metrics, pagination, and sync freshness.
    [BOM.csv, InkPulse.scad, action-button.stl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]
2026-08-16 docs: Generalize product terminology
    Present InkPulse as a reusable application analytics device while keeping the bundled product render as an explicit example configuration.
2026-08-16 docs: Add prototype purchase guide
    Document current reference suppliers and USD estimates so a builder can distinguish per-device material cost from first-order package cost. Preserve validation gates for the exact display, protected 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
